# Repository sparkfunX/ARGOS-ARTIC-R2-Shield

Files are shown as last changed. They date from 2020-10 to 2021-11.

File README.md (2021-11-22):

# ARGOS Satellite Transceiver Shield

The [ARGOS ARTIC R2 satellite communication chipset](https://www.cls-telemetry.com/argos-solutions/argos-products/modems/artic-chipset/#1534863095666-398318f3-c367) in Thing Plus format.

SparkX ARGOS Satellite Transceiver Shield (https://www.sparkfun.com/products/17236)

[*SparkX ARGOS Satellite Transceiver Shield (SPX-17236)*](https://www.sparkfun.com/products/17236)

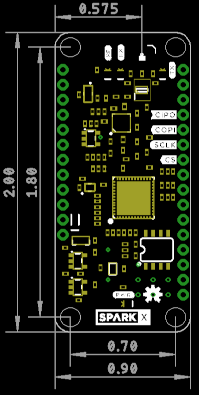
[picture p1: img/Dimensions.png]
Dimensions
_Dimensions are in inches_  

The ARTIC-R2 is an integrated low power small size ARGOS 2/3/4 single chip radio. ARTIC-R2 implements a message based wireless interface. For satellite uplink communication, ARTIC-R2 will encode, modulate and transmit provided user messages. For downlink communication, ARTIC-R2 will lock to the downstream, demodulate and decode it and extract the satellite messages.

The ARTIC-R2 can transmit signals in frequency bands around 400MHz and receive signals in the bands around 466MHz, in accordance with the ARGOS satellite system specifications. The ARTIC-R2 is compliant to all ARGOS 3 and ARGOS 4 RX and TX standards. It contains a RF transceiver and frequency synthesizer and a digital baseband modem. The ARTIC-R2 contains an on-chip power amplifier delivering 1mW [0dBm] output power, that serves as an output for connecting an external high efficient PA. The (de)modulation algorithms run on an on-chip DSP. This software approach allows for retargeting the ARTIC for other applications. The DSP program can be retained on an external flash or the MCU.

- Serial interface (SPI) for communication with MCU
- Programmable DSP core on board to ensure flexibility
- RX frequency : 466MHz – TX frequency: 400MHz
- Fractional N frequency synthesis
- Supported TX standards:
  - BPSK: PTT-A2 (ARGOS 2), PTT-VLD (ARGOS 4)
  - QPSK: PTT-A3, PTT-ZE (ARGOS 3)
  - GMSK: PTT-HD (ARGOS 3), PTT-MD (ARGOS 4), PTT-HD (ARGOS 4)
- Supported RX standards:
  - BPSK: PMT-A3 (ARGOS 3)
  - DSSS OQPSK: PMT-A4 (ARGOS 4) not available
- Dedicated flash Interface to retain Firmware
- Support COSPAS-SARSAT standard
- Operates on external 26MHz reference clock
- Dual supply, 1.8V and 3.3V
- Integrated PA (0dBm) to combine with external PA

An RFPA0133 programmable gain power amplifier boosts the 0dBm (1mW) output from the ARTIC by up to 26dB, producing a maximum transmit power level of 400mW. The transmit power can be adjusted via the **G8** breakout pin.

The ARGOS satellite system is **currently** restricted to specific programs and applications. Please check that your project meets these requirements before buying hardware. [CLS (France)](https://www.cls-telemetry.com/argos-solutions/) and the [Woods Hole Group (America)](https://www.clsamerica.com/science-with-argos) will be able to advise if your project meets the requirements.
- _**"To meet system use requirements, all programs using Argos have to be related in some way or other to environmental protection, awareness or study, or to protecting human life."**_

## Repository Contents

- [**/Documents**](./Documents) - Datasheets, test certificates etc.
- [**/Hardware**](./Hardware) - Eagle PCB, SCH and LBR design files
- [**LICENSE.md**](./LICENSE,md) - contains the licence information

## Documentation

- [**Arduino Library**](https://github.com/sparkfun/SparkFun_ARGOS_ARTIC_R2_Arduino_Library) - SparkFun ARGOS ARTIC R2 Arduino Library
- [**Hookup Guide**](https://learn.sparkfun.com/tutorials/argos-artic-r2-satellite-transceiver-shield-hookup-guide) - a hookup guide for the SparkFun ARGOS Satellite Transceiver Shield - ARTIC R2

## Thanks

The SparkX ARGOS Satellite Transceiver Shield is a remix of the reference design kindly provided by the Arribada Initiative and Icoteq Ltd.

## License Information

This product is _**open source**_! 

Please review the LICENSE.md file for license information. 

If you have any questions or concerns on licensing, please contact technical support on our [SparkFun forums](https://forum.sparkfun.com/viewforum.php?f=152).

Distributed as-is; no warranty is given.

- Your friends at SparkFun.

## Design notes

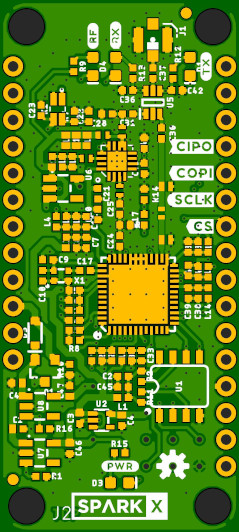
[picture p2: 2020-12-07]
img/Top.JPG

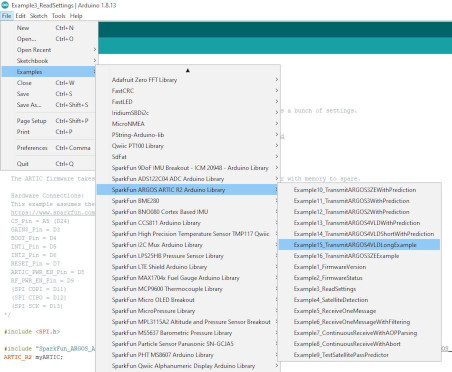
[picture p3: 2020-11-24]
img/HookUp3.JPG

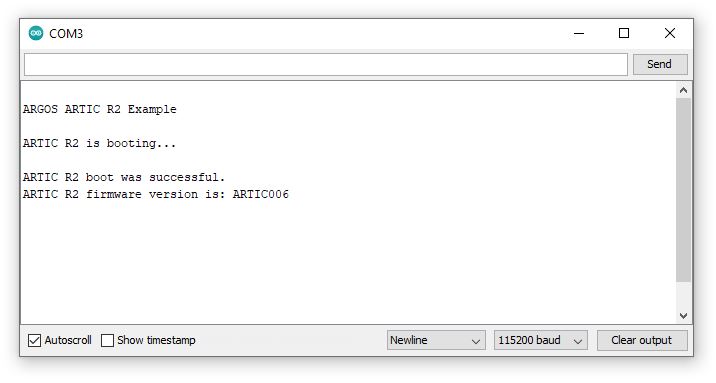
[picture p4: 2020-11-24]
img/HookUp6.JPG

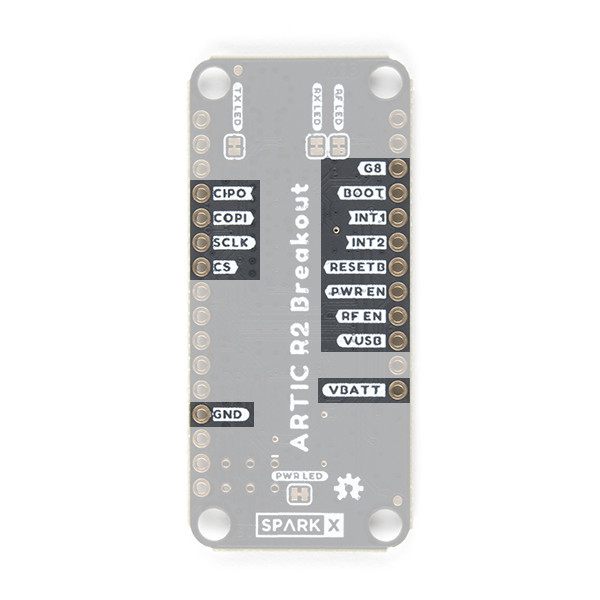
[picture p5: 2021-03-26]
img/17236-Artic_R2_Breakout-03.jpg

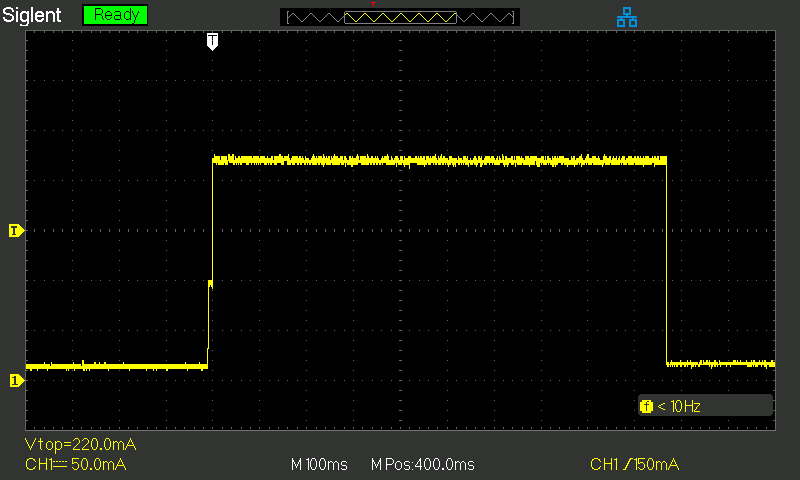
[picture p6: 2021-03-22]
img/TX_Current_ARGOS4VLD.png

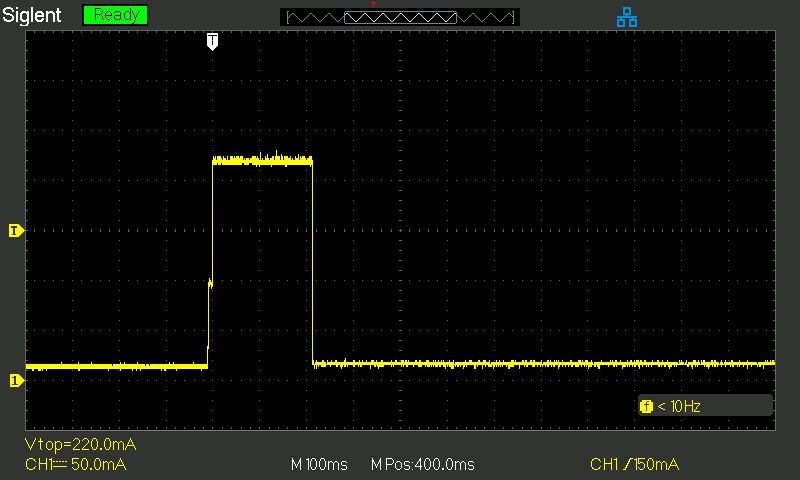
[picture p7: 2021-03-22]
img/TX_Current_ARGOS3ZE.png

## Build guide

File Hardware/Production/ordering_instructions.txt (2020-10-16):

JLCPCB JLC7628 4-Layer 0.8mm Impedance Control
panel size, 107x116mm
PCB thickness, 0.8mm
number of layers, 4
soldermask color, Black
silkscreen color, White
oz copper, 1oz
finish, ENIG
stencils, top
pcs per panel, 8
min trace width, 0.2032mm / 0.0080in
min drill size, 0.2000mm / 0.0079in
filename to layer stackup 1/2/3/4: GTL, GL2, GL3, GBL

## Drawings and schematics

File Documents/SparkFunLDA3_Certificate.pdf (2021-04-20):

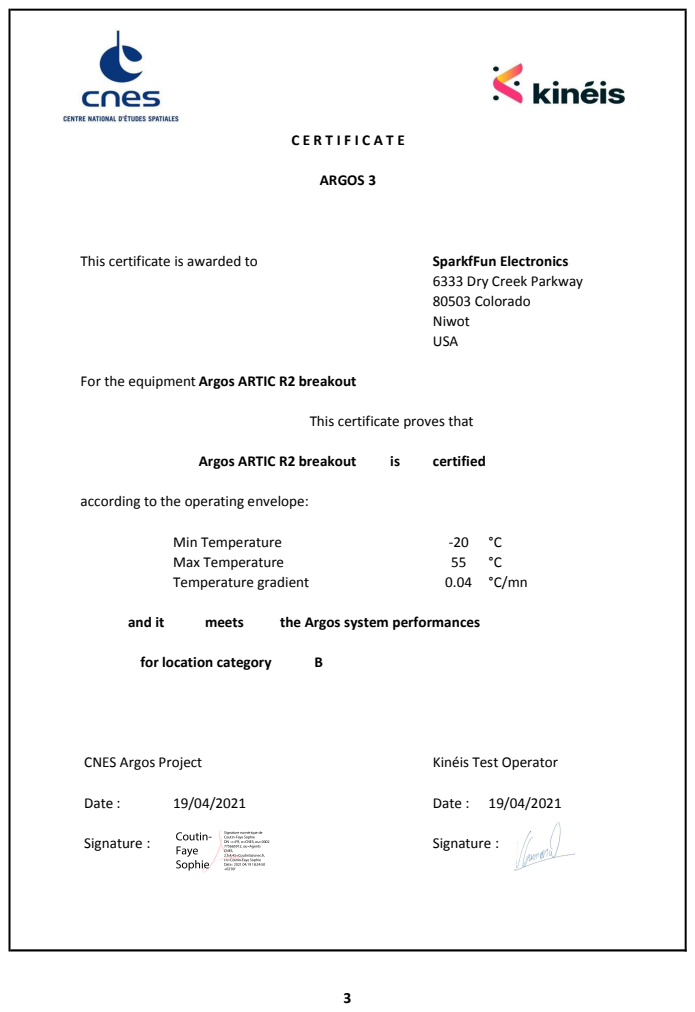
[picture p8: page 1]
This certificate is awarded to; SparkfFun Electronics; Argos ARTIC R2 breakout; certified; Min Temperature; Max Temperature; Temperature gradient; and it; meets; the Argos system performances; for location category; CNES Argos Project; Kinéis Test Operator; Date :; Date : 19/04/2021; Signature :; ARGOS 3

6333 Dry Creek Parkway
80503 Colorado
Niwot
USA

For the equipment Argos ARTIC R2 breakout

This certificate proves that

according to the operating envelope:

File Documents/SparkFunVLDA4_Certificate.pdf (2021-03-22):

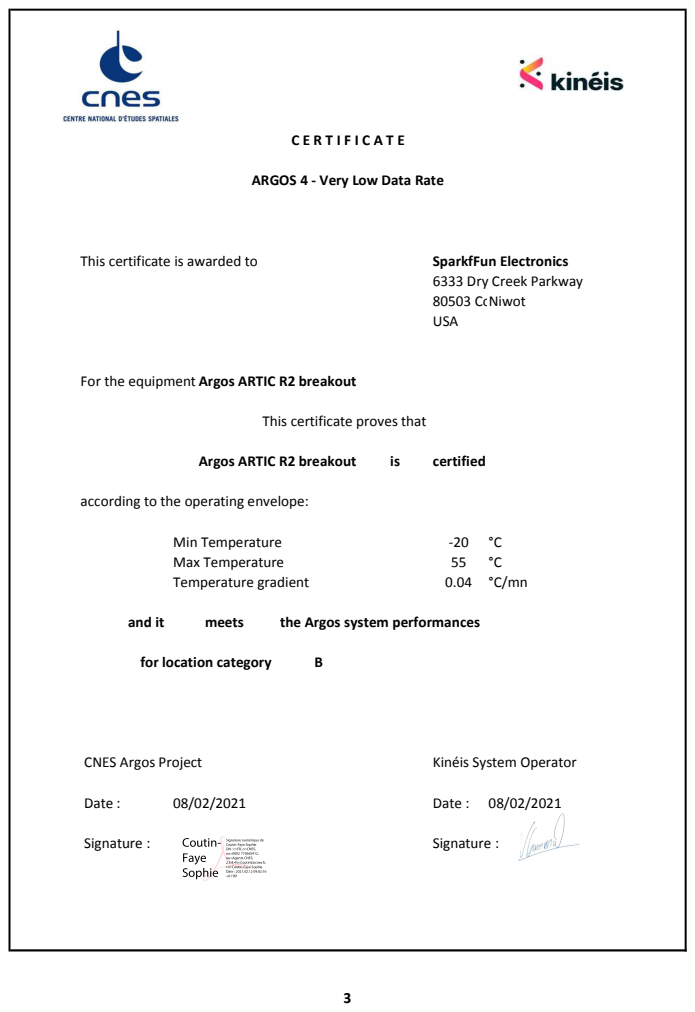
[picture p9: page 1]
This certificate is awarded to; SparkfFun Electronics; Argos ARTIC R2 breakout; certified; Min Temperature; Max Temperature; Temperature gradient; and it; meets; the Argos system performances; for location category; CNES Argos Project; Kinéis System Operator; Date :; Date : 08/02/2021; Signature :

ARGOS 4 - Very Low Data Rate

6333 Dry Creek Parkway
80503 Colorado Niwot
USA

For the equipment Argos ARTIC R2 breakout

This certificate proves that

according to the operating envelope:

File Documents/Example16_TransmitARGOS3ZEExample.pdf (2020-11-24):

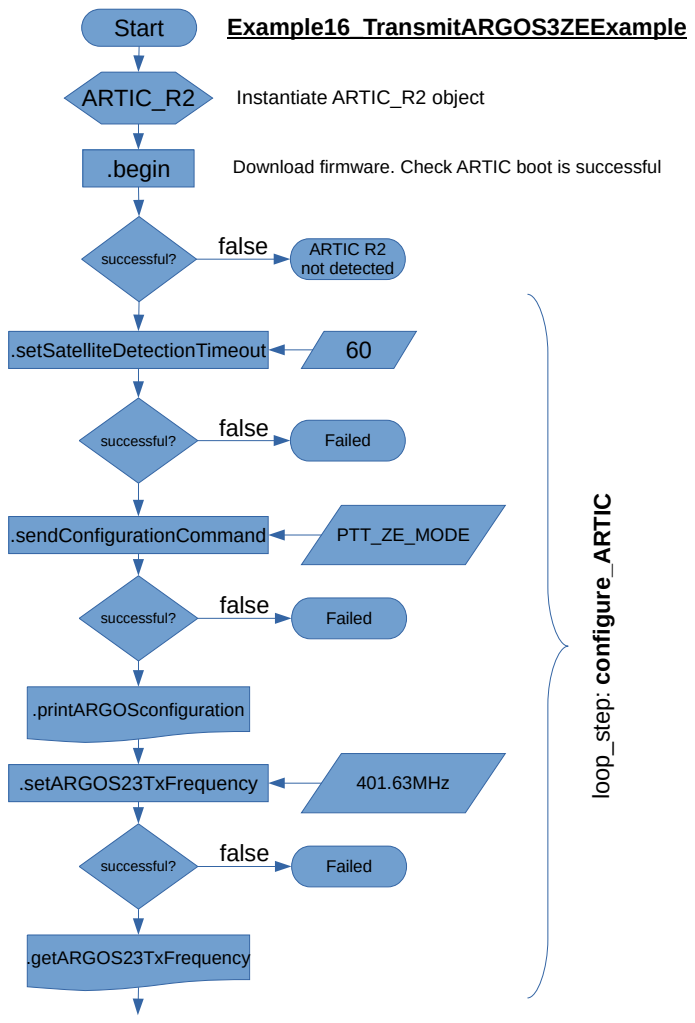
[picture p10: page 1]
Start; ARTIC_R2; Example16_TransmitARGOS3ZEExample; .begin; successful?; ARTIC R2; not detected; false; .setSatelliteDetectionTimeout; Failed false; .sendConfigurationCommand; PTT_ZE_MODE; .printARGOSconfiguration; .setARGOS23TxFrequency; 401.63MHz; .getARGOS23TxFrequency; Instantiate ARTIC_R2 object

Download firmware. Check ARTIC boot is successful

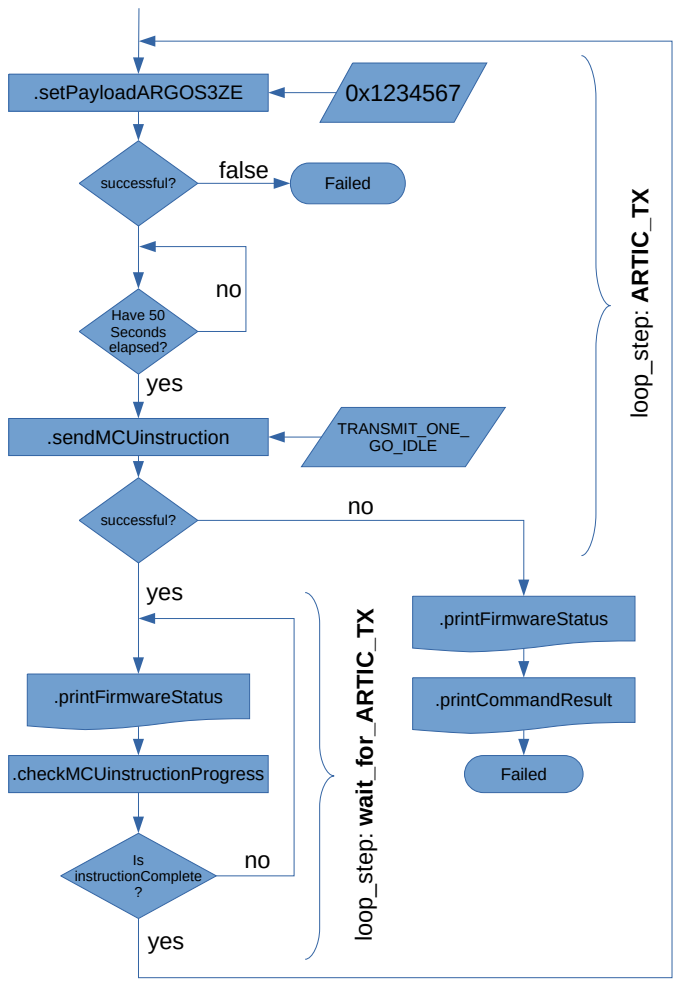
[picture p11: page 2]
.setPayloadARGOS3ZE; successful?; Failed false; Have 50 Seconds elapsed? yes; .sendMCUinstruction; TRANSMIT_ONE_; GO_IDLE; Failed; .printFirmwareStatus; .printCommandResult; yes; .checkMCUinstructionProgress; Is instructionComplete ?; ait_

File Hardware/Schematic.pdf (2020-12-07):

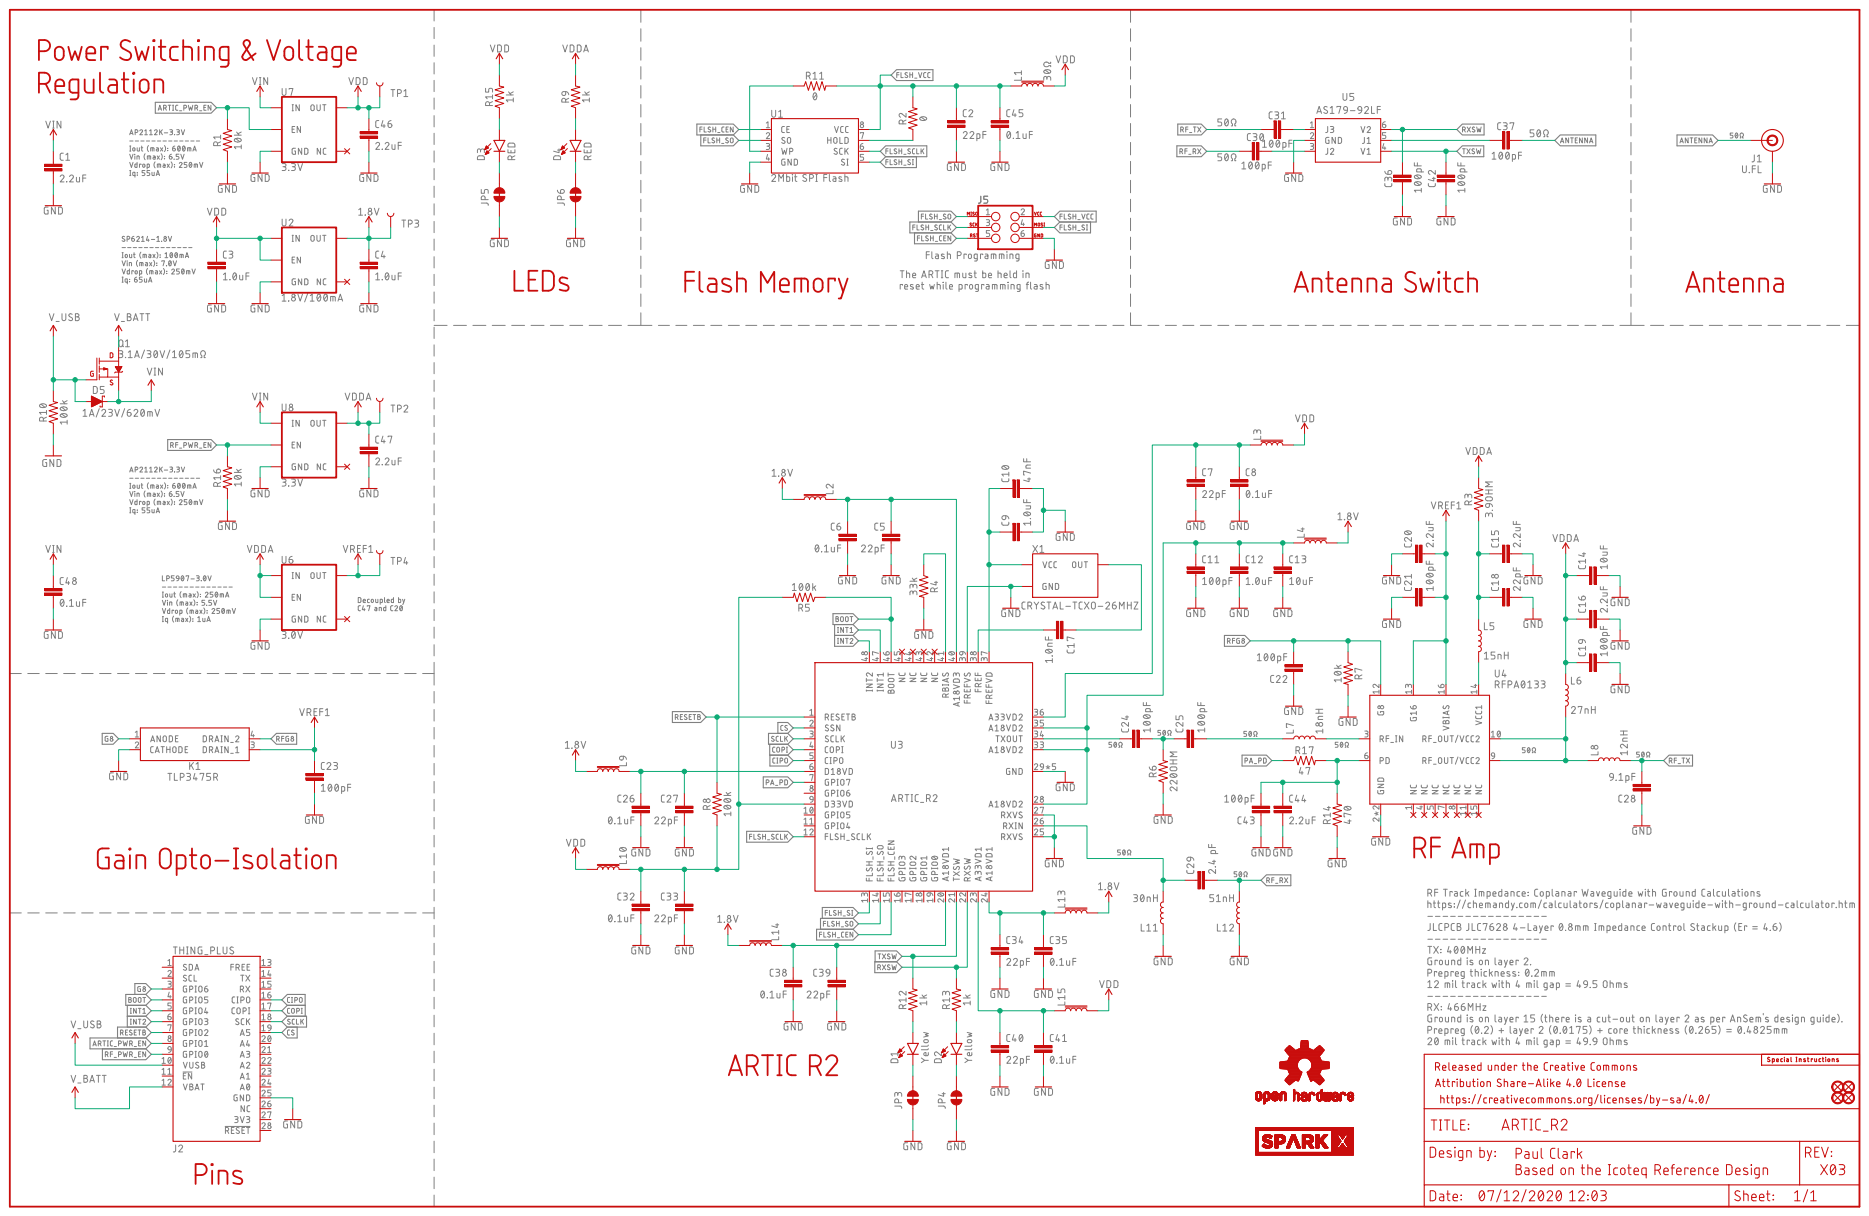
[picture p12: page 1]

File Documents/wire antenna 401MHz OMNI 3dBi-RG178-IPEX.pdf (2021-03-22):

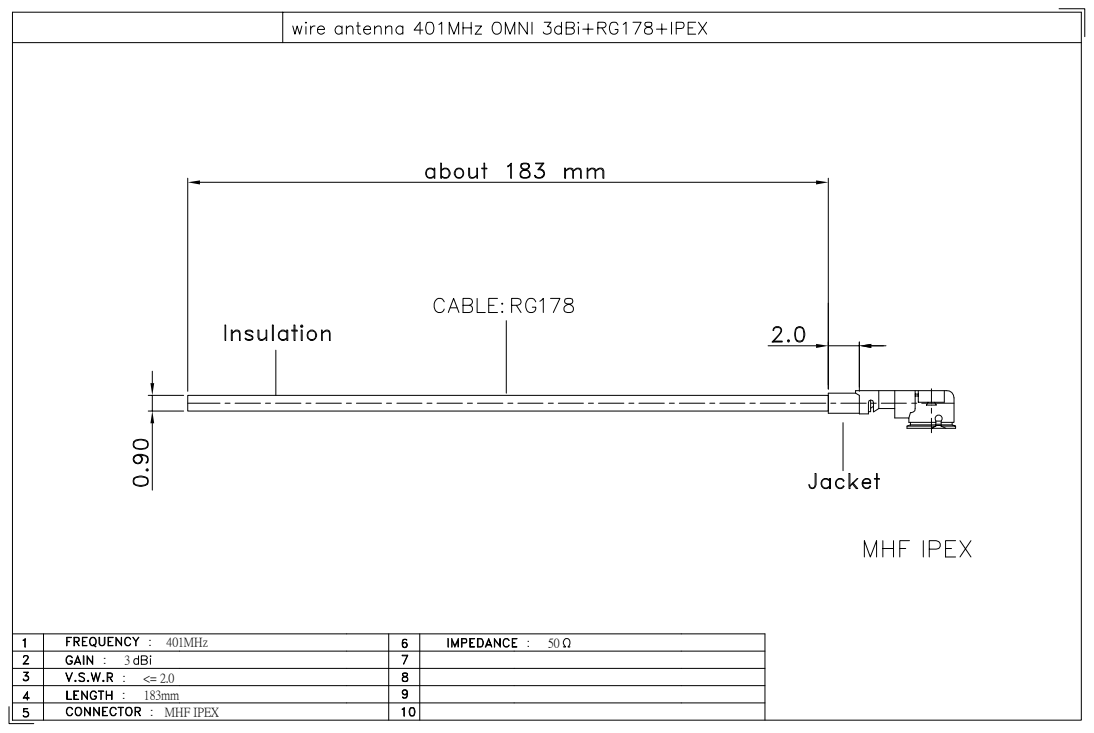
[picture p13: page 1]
: MHF IPEX; 401MHz

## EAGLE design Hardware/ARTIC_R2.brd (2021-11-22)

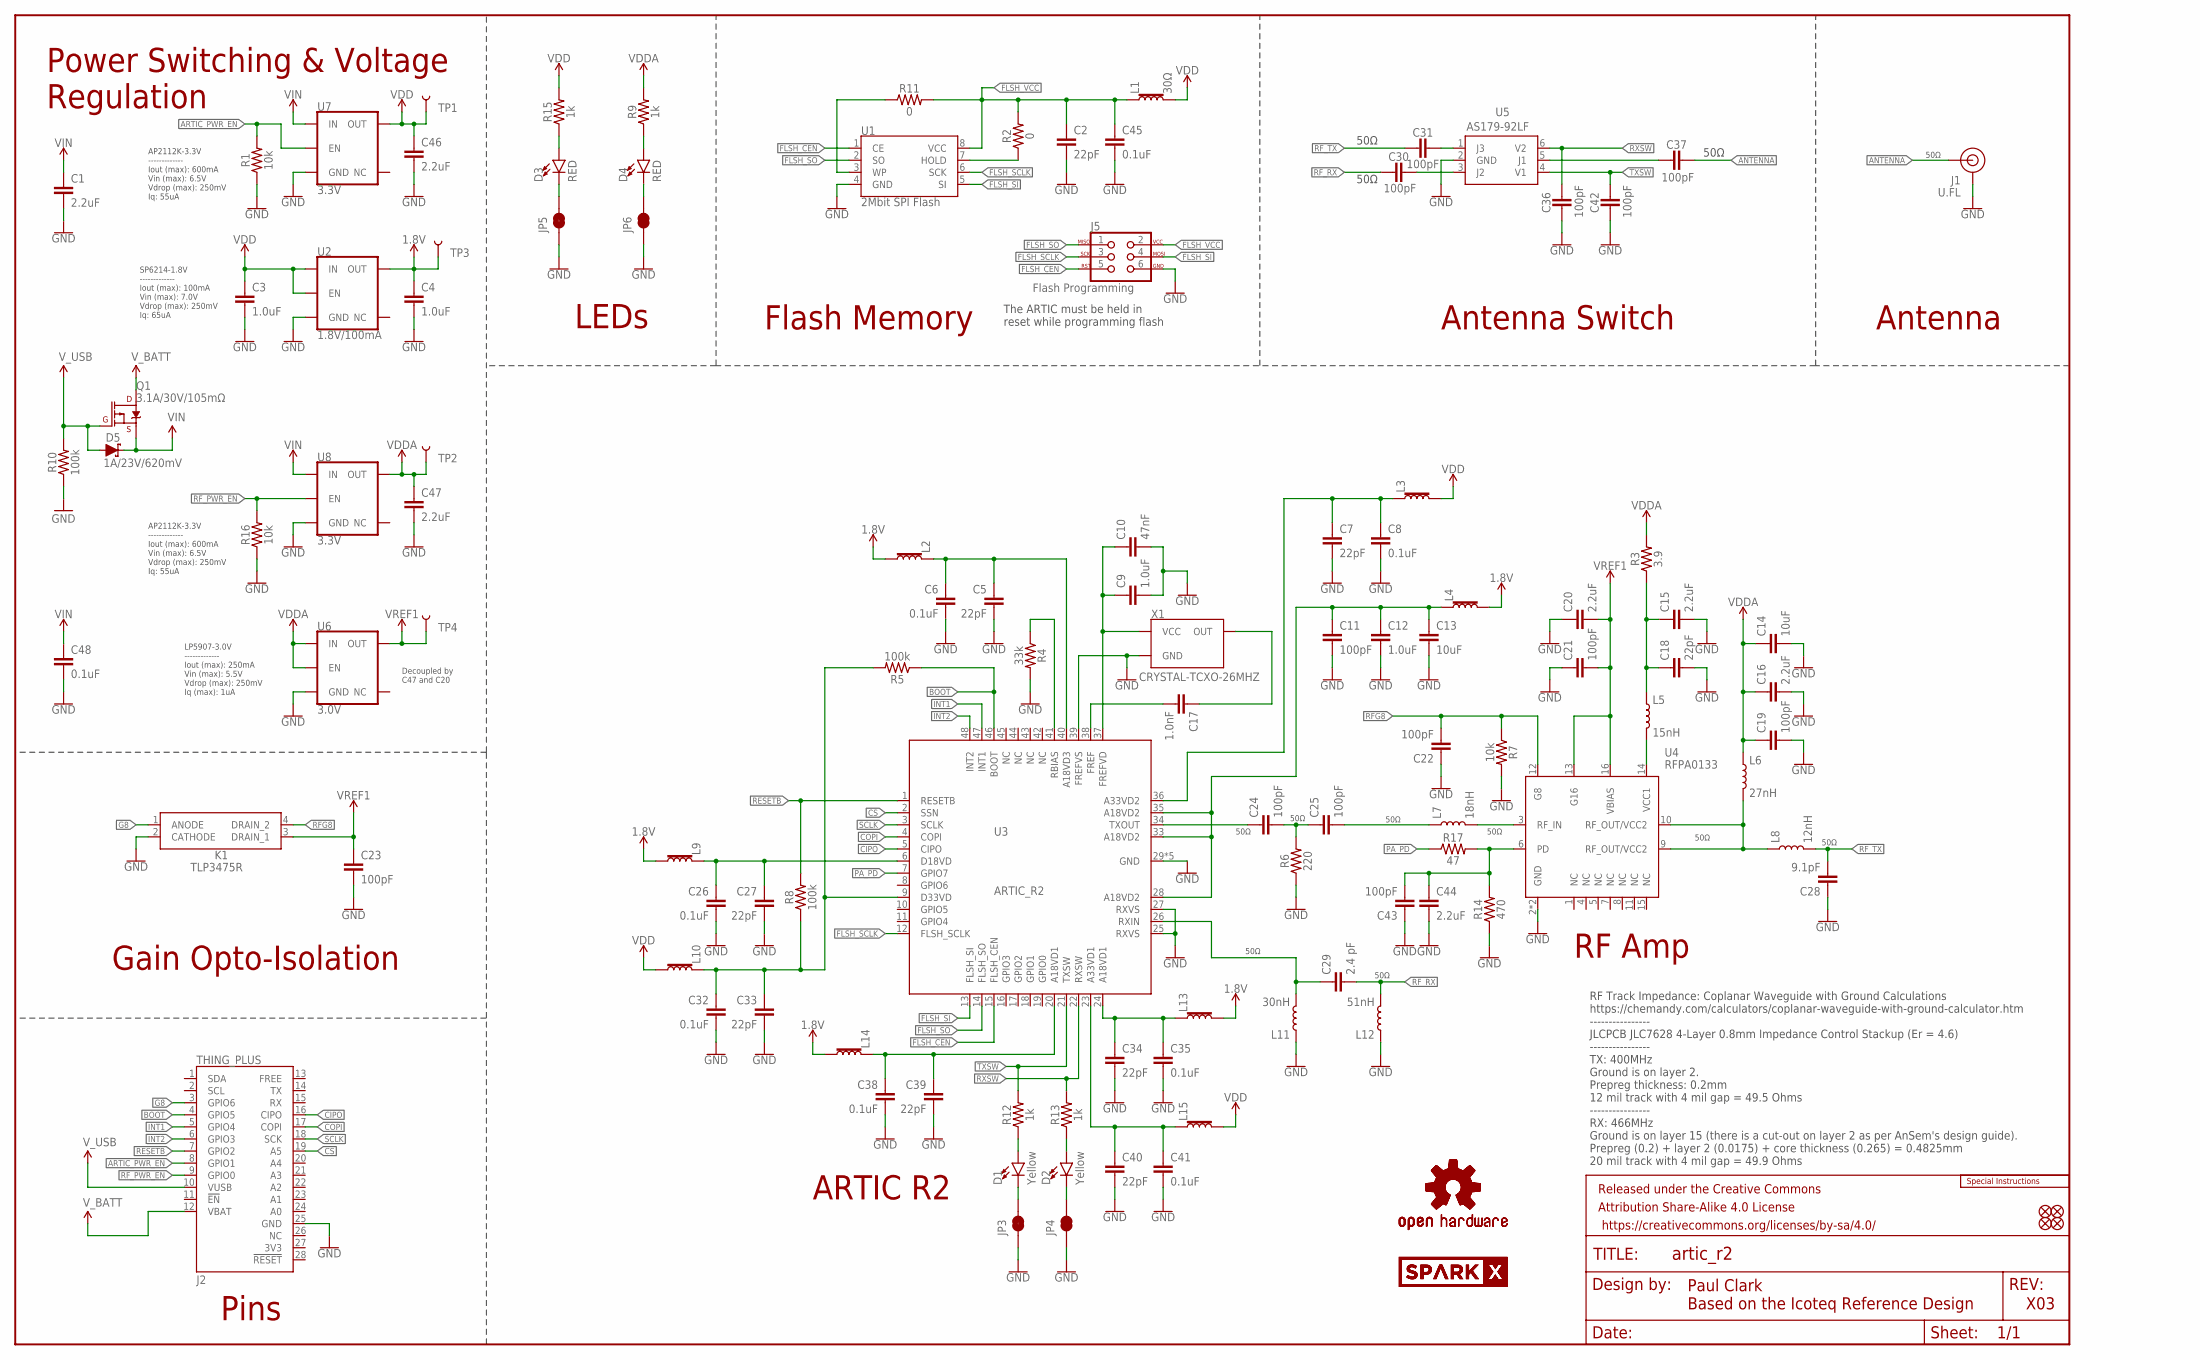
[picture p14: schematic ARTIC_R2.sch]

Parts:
C1, C15, C16, C20, C44, C46, C47: 2.2uF; 0402-TIGHT
C2, C5, C7, C18, C27, C33, C34, C39, C40: 22pF; 0402-TIGHT
C3, C4, C9, C12: 1.0uF; 0402-TIGHT
C6, C8, C26, C32, C35, C38, C41, C45, C48: 0.1uF; 0402-TIGHT
C10: 47nF; 0402-TIGHT
C11, C19, C21, C22, C23, C24, C25, C30, C31, C36, C37, C42, C43: 100pF; 0402-TIGHT
C13, C14: 10uF; 0402-TIGHT
C17: 1.0nF; 0402-TIGHT
C28: 9.1pF; 0402-TIGHT
C29: 2.4 pF; 0402_MURATA
D1, D2: Yellow; LED-0603
D3, D4: RED; LED-0603
D5: 1A/23V/620mV; SOD-323
FD1, FD2, FD3, FD4: FIDUCIAL1X2; FIDUCIAL-1X2
FRAME1: FRAME-LEDGER; CREATIVE_COMMONS
J1: U.FL
J2: THING_PLUS
J5: Flash Programming; 2X3_TEST_POINTS
JP3, JP4, JP5, JP6: JUMPER-SMT_2_NC_TRACE_SILK; SMT-JUMPER_2_NC_TRACE_SILK
K1: TLP3475R; TLP3475RTPF
L1, L2, L3, L4, L9, L10, L13, L14, L15: 30Ω; 0402-TIGHT
L5: 15nH; 0402_COILCRAFT
L6: 27nH; 0402_COILCRAFT
L7: 18nH; 0402_COILCRAFT
L8: 12nH; 0402_COILCRAFT
L11: 30nH; 0402_COILCRAFT
L12: 51nH; 0402_COILCRAFT
LOGO1: SPECIAL_INSTRUCTIONS-ORDERING; ORDERING_INSTRUCTIONS
LOGO2, LOGO3: OSHW-LOGOS; OSHW-LOGO-S
Q1: 3.1A/30V/105mΩ; SOT23-3
R1, R7, R16: 10k; 0402-TIGHT
R2, R11: 0; 0402-TIGHT
R3: 3.9; 0402-TIGHT
R4: 33k; 0402-TIGHT
R5, R8, R10: 100k; 0402-TIGHT
R6: 220; 0402-TIGHT
R9, R12, R13, R15: 1k; 0402-TIGHT
R14: 470; 0402-TIGHT
R17: 47; 0402-TIGHT
SPARKX1, SPARKX2: SPARKX-LOGO4; SPARKX-MEDIUM
TP1, TP2, TP3, TP4: TEST-POINTTP_15TH_THRU; TP_15TH
U1: 2Mbit SPI Flash; SO08
U2: 1.8V/100mA; SC70
U3: ARTIC_R2; QFN-48
U4: RFPA0133; QFN50P300X300X86-17N
U5: AS179-92LF; SOT65P220X100-6N
U6: 3.0V; SOT23-5
U7, U8: 3.3V; SOT23-5
X1: CRYSTAL-TCXO-26MHZ; CRYSTAL-TCXO-SMD-1.65X1.25

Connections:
1.8V: C4.1, L2.2, L4.2, L9.2, L13.2, L14.2, TP3.P$1, U2.5 (OUT)
ANTENNA: C37.1, J1.FEED (SIGNAL)
ARTIC_PWR_EN: J2.8 (GPIO1), R1.2, U7.3 (EN)
BOOT: J2.4 (GPIO5), R5.1, U3.46 (BOOT)
CIPO: J2.16 (CIPO), U3.5 (CIPO)
COPI: J2.17 (COPI), U3.4 (COPI)
CS: J2.19 (A5), U3.2 (SSN)
FLSH_CEN: J5.5, U1.1 (CE), U3.15 (FLSH_CEN)
FLSH_SCLK: J5.3, U1.6 (SCK), U3.12 (FLSH_SCLK)
FLSH_SI: J5.4, U1.5 (SI), U3.13 (FLSH_SI)
FLSH_SO: J5.1, U1.2 (SO), U3.14 (FLSH_SO)
FLSH_VCC: C2.1, C45.1, J5.2, L1.1, R2.2, R11.2, U1.8 (VCC)
G8: J2.3 (GPIO6), K1.1 (ANODE)
GND: C1.2, C2.2, C3.2, C4.2, C5.2, C6.2, C7.2, C8.2, C9.2, C10.2, C11.2, C12.2, C13.2, C14.2, C15.2, C16.2, C18.2, C19.2, C20.1, C21.1, C22.1, C23.2, C26.2, C27.2, C28.1, C32.2, C33.2, C34.2, C35.2, C36.2, C38.2, C39.2, C40.2, C41.2, C42.2, C43.1, C44.2, C45.2, C46.2, C47.2, C48.2, J1.1 (GND), J1.2 (GND), J2.25 (GND), J5.6, JP3.1, JP4.1, JP5.1, JP6.1, K1.2 (CATHODE), L11.P$1 (1), L12.P$1 (1), R1.1, R4.2, R6.1, R7.2, R10.1, R14.1, R16.1, U1.4 (GND), U2.2 (GND), U3.25 (RXVS), U3.27 (RXVS), U3.29 (GND), U3.30 (GND), U3.31 (GND), U3.32 (GND), U3.39 (FREFVS), U3.GND, U4.2 (GND), U4.EDAP (GND), U5.2 (GND), U6.2 (GND), U7.2 (GND), U8.2 (GND), X1.1 (GND), X1.2 (GND)
INT1: J2.5 (GPIO4), U3.47 (INT1)
INT2: J2.6 (GPIO3), U3.48 (INT2)
unnamed: R2.1, U1.7 (HOLD)
unnamed: R11.1, U1.3 (WP)
unnamed: C34.1, C35.1, L13.1, U3.24 (A18VD1)
unnamed: C40.1, C41.1, L15.1, U3.23 (A33VD1)
unnamed: D2.A, R13.1
unnamed: D1.A, R12.1
unnamed: C26.1, C27.1, L9.1, U3.6 (D18VD)
unnamed: C32.1, C33.1, L10.1, R5.2, R8.1, U3.9 (D33VD)
unnamed: C11.1, C12.1, C13.1, L4.1, U3.28 (A18VD2), U3.33 (A18VD2), U3.35 (A18VD2)
unnamed: C7.1, C8.1, L3.1, U3.36 (A33VD2)
unnamed: R4.1, U3.41 (RBIAS)
unnamed: C5.1, C6.1, L2.1, U3.40 (A18VD3)
unnamed: C9.1, C10.1, U3.37 (FREFVD), X1.4 (VCC)
unnamed: C17.1, X1.3 (OUT)
unnamed: C17.2, U3.38 (FREF)
unnamed: C24.1, U3.34 (TXOUT)
unnamed: C24.2, C25.1, R6.2
unnamed: L5.P$2 (2), U4.14 (VCC1)
unnamed: C15.1, C18.1, L5.P$1 (1), R3.1
unnamed: C29.P$1 (1), L11.P$2 (2), U3.26 (RXIN)
unnamed: D4.A, R9.1
unnamed: C25.2, L7.P$1 (1)
unnamed: L7.P$2 (2), U4.3 (RF_IN)
unnamed: L6.P$2 (2), L8.P$1 (1), U4.9 (RF_OUT/VCC2), U4.10 (RF_OUT/VCC2)
unnamed: D4.C, JP6.2
unnamed: C31.1, U5.1 (J3)
unnamed: C30.1, U5.3 (J2)
unnamed: C37.2, U5.5 (J1)
unnamed: C38.1, C39.1, L14.1, U3.20 (A18VD1)
unnamed: D1.C, JP3.2
unnamed: D2.C, JP4.2
unnamed: D3.A, R15.1
unnamed: D3.C, JP5.2
PA_PD: R17.1, U3.7 (GPIO7)
PD: C43.2, C44.1, R14.2, R17.2, U4.6 (PD)
RESETB: J2.7 (GPIO2), R8.2, U3.1 (RESETB)
RFG8: C22.2, K1.4 (DRAIN_2), R7.1, U4.12 (G8)
RF_PWR_EN: J2.9 (GPIO0), R16.2, U8.3 (EN)
RF_RX: C29.P$2 (2), C30.2, L12.P$2 (2)
RF_TX: C28.2, C31.2, L8.P$2 (2)
RXSW: C36.1, R13.2, U3.22 (RXSW), U5.6 (V2)
SCLK: J2.18 (SCK), U3.3 (SCLK)
TXSW: C42.1, R12.2, U3.21 (TXSW), U5.4 (V1)
VDD: C3.1, C46.1, L1.2, L3.2, L10.2, L15.2, R15.2, TP1.P$1, U2.1 (IN), U2.3 (EN), U7.5 (OUT)
VDDA: C14.1, C16.1, C19.1, C47.1, L6.P$1 (1), R3.2, R9.2, TP2.P$1, U6.1 (IN), U6.3 (EN), U8.5 (OUT)
VIN: C1.1, C48.1, D5.C, Q1.2 (S), U7.1 (IN), U8.1 (IN)
VREF1: C20.2, C21.2, C23.1, K1.3 (DRAIN_1), TP4.P$1, U4.13 (G16), U4.16 (VBIAS), U6.5 (OUT)
V_BATT: J2.12 (VBAT), Q1.3 (D)
V_USB: D5.A, J2.10 (VUSB), Q1.1 (G), R10.2

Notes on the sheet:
Paul Clark Based on the Icoteq Reference Design
X03
SP6214-1.8V ------------- Iout (max): 100mA Vin (max): 7.0V Vdrop (max): 250mV Iq: 65uA
Power Switching & Voltage Regulation
Flash Memory
Antenna Switch
Antenna
ARTIC R2
RF Amp
Pins
50Ω
LEDs
RF Track Impedance: Coplanar Waveguide with Ground Calculations https://chemandy.com/calculators/coplanar-waveguide-with-ground-calculator.htm ---------------- JLCPCB JLC7628 4-Layer 0.8mm Impedance Control Stackup (Er = 4.6) ---------------- TX: 400MHz Ground is on layer 2. Prepreg thickness: 0.2m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
Gain Opto-Isolation
The ARTIC must be held in reset while programming flash
AP2112K-3.3V ------------- Iout (max): 600mA Vin (max): 6.5V Vdrop (max): 250mV Iq: 55uA
LP5907-3.0V ------------- Iout (max): 250mA Vin (max): 5.5V Vdrop (max): 250mV Iq (max): 1uA
Decoupled by C47 and C20

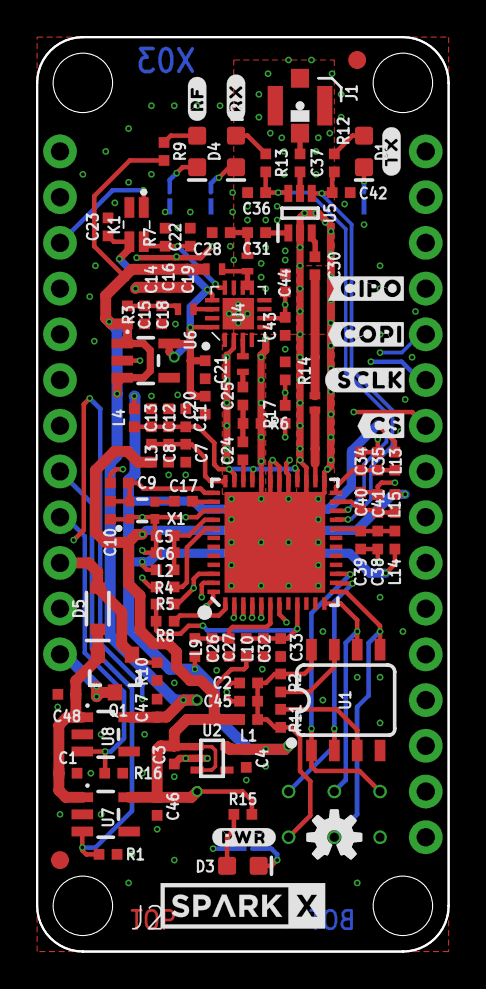
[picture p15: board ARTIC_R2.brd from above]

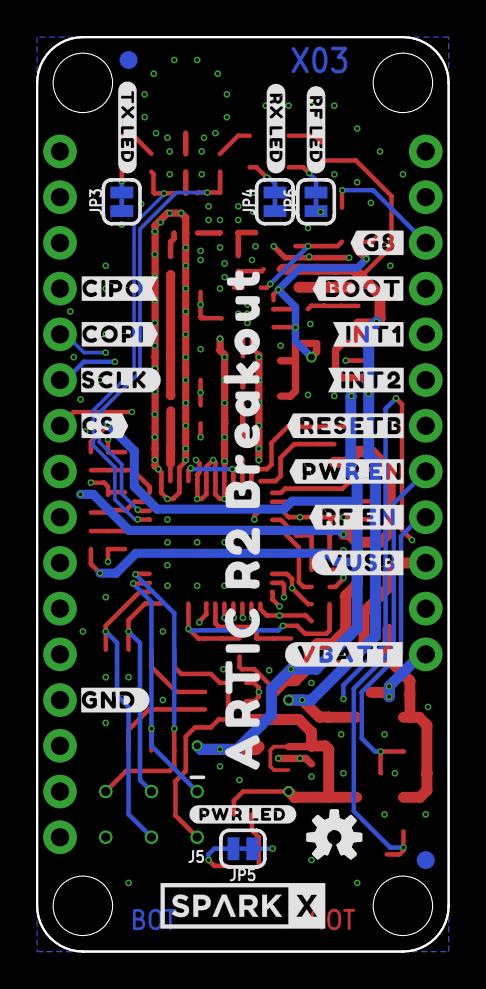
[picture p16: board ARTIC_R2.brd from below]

Board: 4 copper layers, 22.9 x 50.8 mm, 144 parts (28 on the bottom side), 65 nets.

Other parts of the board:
U$1: #TX#0
U$2: #RX#0
U$3: #RX_LED#0
U$4: #TX_LED#0
U$5: #RF_LED#0
U$6: #G8#0
U$7: #RF#0
U$8: #RF_EN#0
U$9: CIPO#0
U$10: #CIPO0
U$11: #COPI0
U$12: COPI#0
U$13: #SCLK0
U$14: SCLK#0
U$15: #CS0
U$16: CS#0
U$17: GND#0
U$18: #RESETB0
U$19: #PWR_EN0
U$20: #VBATT#0
U$21: #VUSB#0
U$24: #BOOT0
U$25: #INT10
U$26: #INT20
U$27: #PWR_LED#0
U$28: #PWR#0
U$29: ARTIC_R2_BREAKOUT0

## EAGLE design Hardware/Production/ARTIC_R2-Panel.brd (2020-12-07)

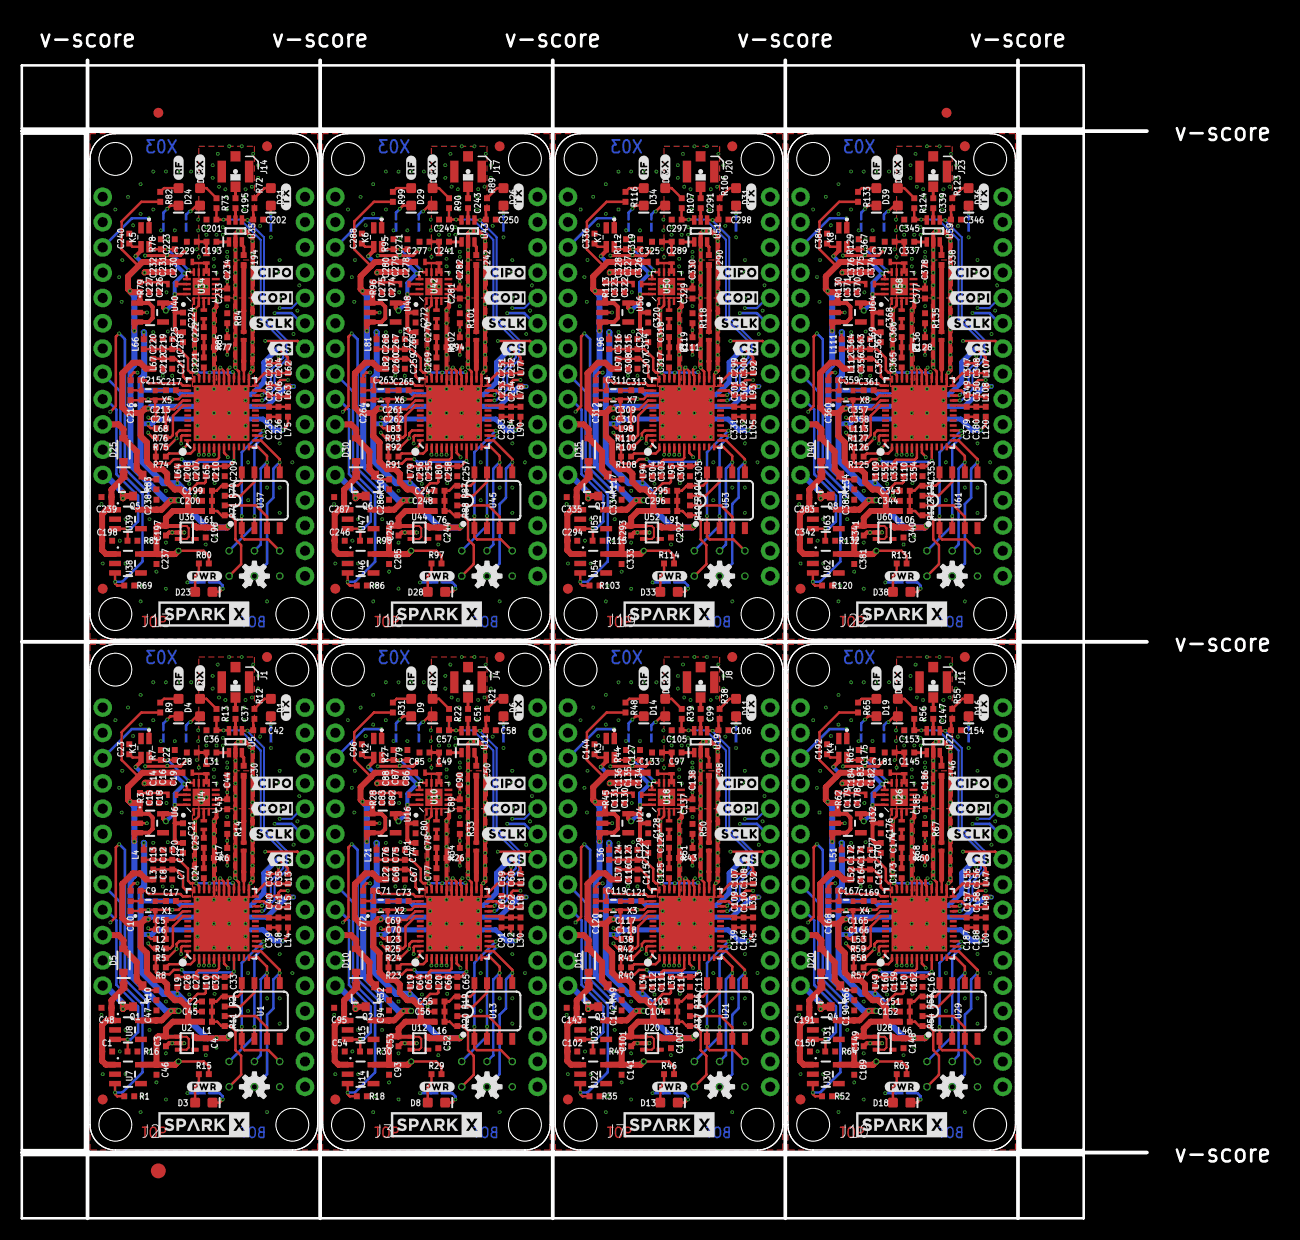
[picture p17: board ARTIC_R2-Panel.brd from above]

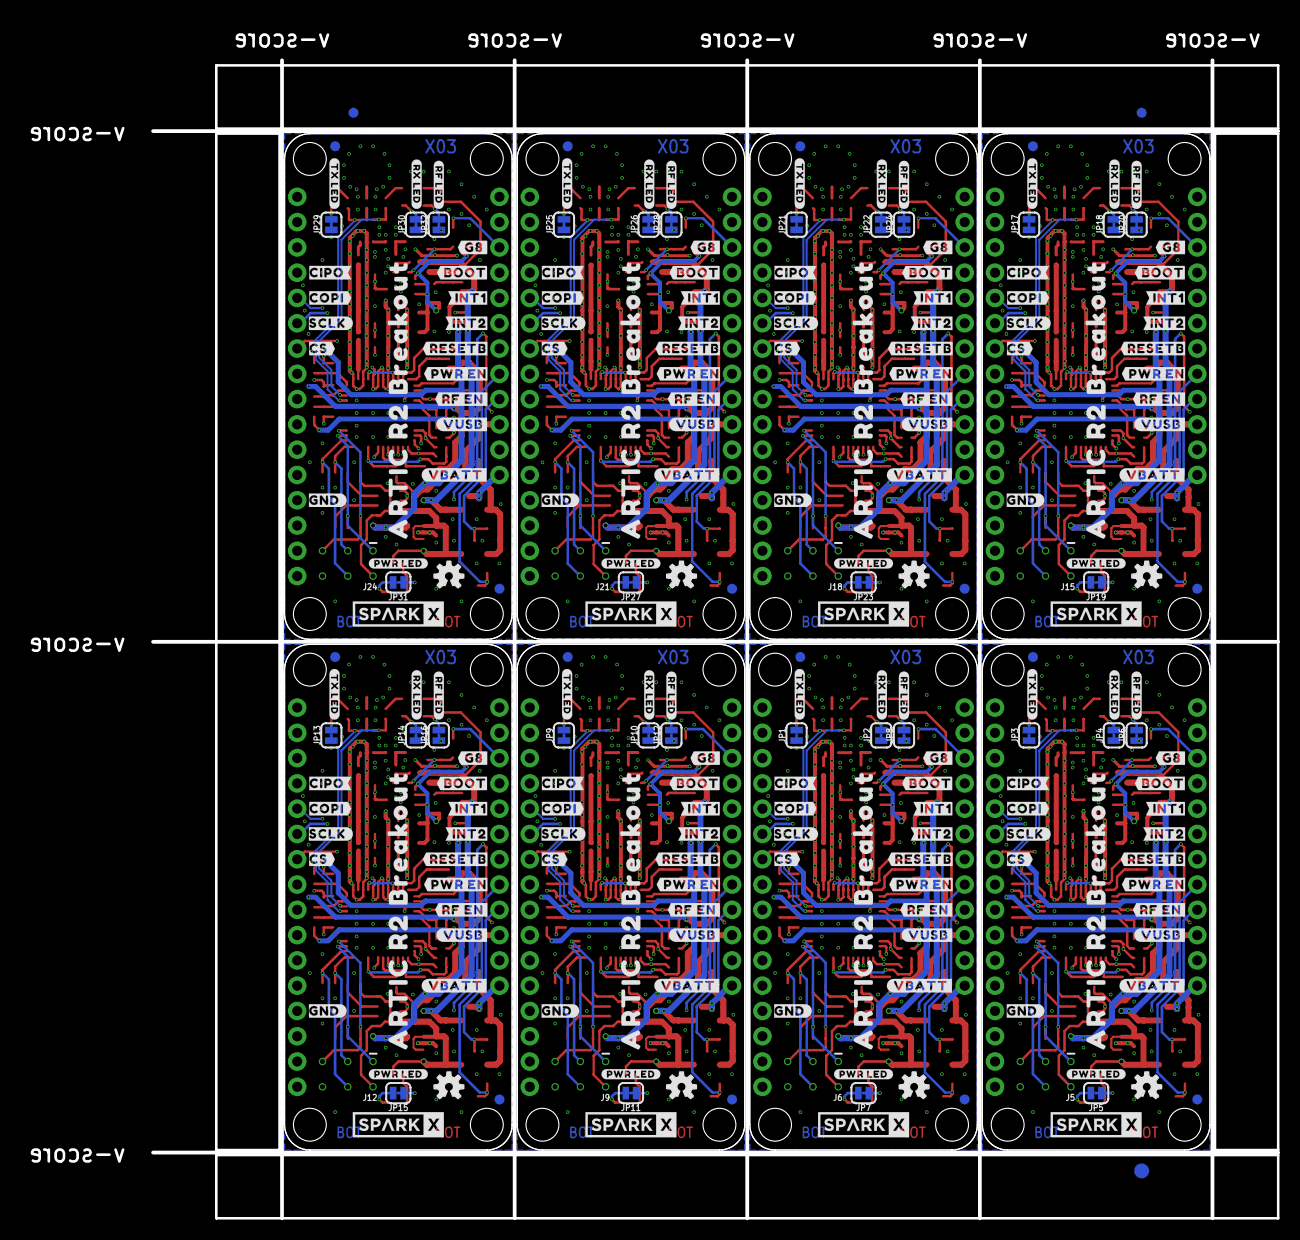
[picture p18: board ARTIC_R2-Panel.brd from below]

Board: 4 copper layers, 113.0 x 116.3 mm, 1142 parts (227 on the bottom side), 520 nets.

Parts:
C1, C15, C16, C20, C44, C46, C47, C54, C81, C83, C87, C90, C93, C94, C102, C129, C131, C135, C138, C141, C142, C150, C177, C179, C183, C186, C189, C190, C198, C225, C227, C231, C234, C237, C238, C246, C273, C275, C279, C282, C285, C286, C294, C321, C323, C327, C330, C333, C334, C342, C369, C371, C375, C378, C381, C382: 2.2uF; 0402-TIGHT
C2, C5, C7, C18, C27, C33, C34, C39, C40, C55, C59, C61, C63, C65, C67, C69, C82, C91, C103, C107, C109, C111, C113, C115, C117, C130, C139, C151, C155, C157, C159, C161, C163, C165, C178, C187, C199, C203, C205, C207, C209, C211, C213, C226, C235, C247, C251, C253, C255, C257, C259, C261, C274, C283, C295, C299, C301, C303, C305, C307, C309, C322, C331, C343, C347, C349, C351, C353, C355, C357, C370, C379: 22pF; 0402-TIGHT
C3, C4, C9, C12, C52, C53, C71, C75, C100, C101, C119, C123, C148, C149, C167, C171, C196, C197, C215, C219, C244, C245, C263, C267, C292, C293, C311, C315, C340, C341, C359, C363: 1.0uF; 0402-TIGHT
C6, C8, C26, C32, C35, C38, C41, C45, C48, C56, C60, C62, C64, C66, C68, C70, C92, C95, C104, C108, C110, C112, C114, C116, C118, C140, C143, C152, C156, C158, C160, C162, C164, C166, C188, C191, C200, C204, C206, C208, C210, C212, C214, C236, C239, C248, C252, C254, C256, C258, C260, C262, C284, C287, C296, C300, C302, C304, C306, C308, C310, C332, C335, C344, C348, C350, C352, C354, C356, C358, C380, C383: 0.1uF; 0402-TIGHT
C10, C72, C120, C168, C216, C264, C312, C360: 47nF; 0402-TIGHT
C11, C19, C21, C22, C23, C24, C25, C30, C31, C36, C37, C42, C43, C49, C50, C51, C57, C58, C74, C77, C78, C79, C80, C86, C89, C96, C97, C98, C99, C105, C106, C122, C125, C126, C127, C128, C134, C137, C144, C145, C146, C147, C153, C154, C170, C173, C174, C175, C176, C182, C185, C192, C193, C194, C195, C201, C202, C218, C221, C222, C223, C224, C230, C233, C240, C241, C242, C243, C249, C250, C266, C269, C270, C271, C272, C278, C281, C288, C289, C290, C291, C297, C298, C314, C317, C318, C319, C320, C326, C329, C336, C337, C338, C339, C345, C346, C362, C365, C366, C367, C368, C374, C377, C384: 100pF; 0402-TIGHT
C13, C14, C76, C88, C124, C136, C172, C184, C220, C232, C268, C280, C316, C328, C364, C376: 10uF; 0402-TIGHT
C17, C73, C121, C169, C217, C265, C313, C361: 1.0nF; 0402-TIGHT
C28, C85, C133, C181, C229, C277, C325, C373: 9.1pF; 0402-TIGHT
C29, C84, C132, C180, C228, C276, C324, C372: 2.4 pF; 0402_MURATA
D1, D2, D6, D7, D11, D12, D16, D17, D21, D22, D26, D27, D31, D32, D36, D37: Yellow; LED-0603
D3, D4, D8, D9, D13, D14, D18, D19, D23, D24, D28, D29, D33, D34, D38, D39: RED; LED-0603
D5, D10, D15, D20, D25, D30, D35, D40: 1A/23V/620mV; SOD-323
E$1, E$2, E$3, E$4: FIDUCIAL-1X2
E$5, E$6: FIDUCIAL-1.5X3
FD1, FD2, FD3, FD4, FD5, FD6, FD7, FD8, FD9, FD10, FD11, FD12, FD13, FD14, FD15, FD16, FD17, FD18, FD19, FD20, FD21, FD22, FD23, FD24, FD25, FD26, FD27, FD28, FD29, FD30, FD31, FD32: FIDUCIAL1X2; FIDUCIAL-1X2
J1, J4, J8, J11, J14, J17, J20, J23: U.FL
J2, J3, J7, J10, J13, J16, J19, J22: THING_PLUS
J5, J6, J9, J12, J15, J18, J21, J24: Flash Programming; 2X3_TEST_POINTS
JP1, JP2, JP3, JP4, JP5, JP6, JP7, JP8, JP9, JP10, JP11, JP12, JP13, JP14, JP15, JP16, JP17, JP18, JP19, JP20, JP21, JP22, JP23, JP24, JP25, JP26, JP27, JP28, JP29, JP30, JP31, JP32: JUMPER-SMT_2_NC_TRACE_SILK; SMT-JUMPER_2_NC_TRACE_SILK
K1, K2, K3, K4, K5, K6, K7, K8: TLP3475R; TLP3475RTPF
L1, L2, L3, L4, L9, L10, L13, L14, L15, L16, L17, L18, L19, L20, L21, L22, L23, L30, L31, L32, L33, L34, L35, L36, L37, L38, L45, L46, L47, L48, L49, L50, L51, L52, L53, L60, L61, L62, L63, L64, L65, L66, L67, L68, L75, L76, L77, L78, L79, L80, L81, L82, L83, L90, L91, L92, L93, L94, L95, L96, L97, L98, L105, L106, L107, L108, L109, L110, L111, L112, L113, L120: 30Ω; 0402-TIGHT
L5, L25, L40, L55, L70, L85, L100, L115: 15nH; 0402_COILCRAFT
L6, L26, L41, L56, L71, L86, L101, L116: 27nH; 0402_COILCRAFT
L7, L24, L39, L54, L69, L84, L99, L114: 18nH; 0402_COILCRAFT
L8, L27, L42, L57, L72, L87, L102, L117: 12nH; 0402_COILCRAFT
L11, L28, L43, L58, L73, L88, L103, L118: 30nH; 0402_COILCRAFT
L12, L29, L44, L59, L74, L89, L104, L119: 51nH; 0402_COILCRAFT
LOGO1, LOGO2, LOGO3, LOGO4, LOGO5, LOGO6, LOGO7, LOGO8, LOGO9, LOGO10, LOGO11, LOGO12, LOGO13, LOGO14, LOGO15, LOGO16: OSHW-LOGOS; OSHW-LOGO-S
Q1, Q2, Q3, Q4, Q5, Q6, Q7, Q8: 3.1A/30V/105mΩ; SOT23-3
R1, R7, R16, R18, R27, R30, R35, R44, R47, R52, R61, R64, R69, R78, R81, R86, R95, R98, R103, R112, R115, R120, R129, R132: 10k; 0402-TIGHT
R2, R11, R19, R20, R36, R37, R53, R54, R70, R71, R87, R88, R104, R105, R121, R122: 0; 0402-TIGHT
R3, R28, R45, R62, R79, R96, R113, R130: 3.9OHM; 0402-TIGHT
R4, R25, R42, R59, R76, R93, R110, R127: 33k; 0402-TIGHT
R5, R8, R10, R23, R24, R32, R40, R41, R49, R57, R58, R66, R74, R75, R83, R91, R92, R100, R108, R109, R117, R125, R126, R134: 100k; 0402-TIGHT
R6, R26, R43, R60, R77, R94, R111, R128: 220OHM; 0402-TIGHT
R9, R12, R13, R15, R21, R22, R29, R31, R38, R39, R46, R48, R55, R56, R63, R65, R72, R73, R80, R82, R89, R90, R97, R99, R106, R107, R114, R116, R123, R124, R131, R133: 1k; 0402-TIGHT
R14, R33, R50, R67, R84, R101, R118, R135: 470; 0402-TIGHT
R17, R34, R51, R68, R85, R102, R119, R136: 47; 0402-TIGHT
SPARKX1, SPARKX2, SPARKX3, SPARKX4, SPARKX5, SPARKX6, SPARKX7, SPARKX8, SPARKX9, SPARKX10, SPARKX11, SPARKX12, SPARKX13, SPARKX14, SPARKX15, SPARKX16: SPARKX-LOGO4; SPARKX-MEDIUM
TP1, TP2, TP3, TP4, TP5, TP6, TP7, TP8, TP9, TP10, TP11, TP12, TP13, TP14, TP15, TP16, TP17, TP18, TP19, TP20, TP21, TP22, TP23, TP24, TP25, TP26, TP27, TP28, TP29, TP30, TP31, TP32: TEST-POINTTP_15TH_THRU; TP_15TH
U1, U13, U21, U29, U37, U45, U53, U61: 2Mbit SPI Flash; SO08
U2, U12, U20, U28, U36, U44, U52, U60: 1.8V/100mA; SC70
U3, U9, U17, U25, U33, U41, U49, U57: ARTIC_R2; QFN-48
U4, U10, U18, U26, U34, U42, U50, U58: RFPA0133; QFN50P300X300X86-17N
U5, U11, U19, U27, U35, U43, U51, U59: AS179-92LF; SOT65P220X100-6N
U6, U16, U24, U32, U40, U48, U56, U64: 3.0V; SOT23-5
U7, U8, U14, U15, U22, U23, U30, U31, U38, U39, U46, U47, U54, U55, U62, U63: 3.3V; SOT23-5
U$1, U$30, U$57, U$84, U$111, U$138, U$165, U$192: #TX#0
U$2, U$31, U$58, U$85, U$112, U$139, U$166, U$193: #RX#0
U$3, U$22, U$55, U$82, U$109, U$136, U$163, U$190: #RX_LED#0
U$4, U$23, U$56, U$83, U$110, U$137, U$164, U$191: #TX_LED#0
U$5, U$49, U$76, U$103, U$130, U$157, U$184, U$211: #RF_LED#0
U$6, U$54, U$81, U$108, U$135, U$162, U$189, U$216: #G8#0
U$7, U$50, U$77, U$104, U$131, U$158, U$185, U$212: #RF#0
U$8, U$51, U$78, U$105, U$132, U$159, U$186, U$213: #RF_EN#0
U$9, U$32, U$59, U$86, U$113, U$140, U$167, U$194: CIPO#0
U$10, U$33, U$60, U$87, U$114, U$141, U$168, U$195: #CIPO0
U$11, U$34, U$61, U$88, U$115, U$142, U$169, U$196: #COPI0
U$12, U$35, U$62, U$89, U$116, U$143, U$170, U$197: COPI#0
U$13, U$36, U$63, U$90, U$117, U$144, U$171, U$198: #SCLK0
U$14, U$37, U$64, U$91, U$118, U$145, U$172, U$199: SCLK#0
U$15, U$38, U$65, U$92, U$119, U$146, U$173, U$200: #CS0
U$16, U$39, U$66, U$93, U$120, U$147, U$174, U$201: CS#0
U$17, U$43, U$70, U$97, U$124, U$151, U$178, U$205: GND#0
U$18, U$41, U$68, U$95, U$122, U$149, U$176, U$203: #RESETB0
U$19, U$42, U$69, U$96, U$123, U$150, U$177, U$204: #PWR_EN0
U$20, U$52, U$79, U$106, U$133, U$160, U$187, U$214: #VBATT#0
U$21, U$53, U$80, U$107, U$134, U$161, U$188, U$215: #VUSB#0
U$24, U$40, U$67, U$94, U$121, U$148, U$175, U$202: #BOOT0
U$25, U$45, U$72, U$99, U$126, U$153, U$180, U$207: #INT10
U$26, U$44, U$71, U$98, U$125, U$152, U$179, U$206: #INT20
U$27, U$46, U$73, U$100, U$127, U$154, U$181, U$208: #PWR_LED#0
U$28, U$47, U$74, U$101, U$128, U$155, U$182, U$209: #PWR#0
U$29, U$48, U$75, U$102, U$129, U$156, U$183, U$210: ARTIC_R2_BREAKOUT0
X1, X2, X3, X4, X5, X6, X7, X8: CRYSTAL-TCXO-26MHZ; CRYSTAL-TCXO-SMD-1.65X1.25

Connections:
1.8V: C4.1, L2.2, L4.2, L9.2, L13.2, L14.2, TP3.P$1, U2.5
1.8V1: C52.1, L17.2, L19.2, L21.2, L23.2, L30.2, TP7.P$1, U12.5
1.8V2: C100.1, L32.2, L34.2, L36.2, L38.2, L45.2, TP11.P$1, U20.5
1.8V3: C148.1, L47.2, L49.2, L51.2, L53.2, L60.2, TP15.P$1, U28.5
1.8V4: C196.1, L62.2, L64.2, L66.2, L68.2, L75.2, TP19.P$1, U36.5
1.8V5: C244.1, L77.2, L79.2, L81.2, L83.2, L90.2, TP23.P$1, U44.5
1.8V6: C292.1, L92.2, L94.2, L96.2, L98.2, L105.2, TP27.P$1, U52.5
1.8V7: C340.1, L107.2, L109.2, L111.2, L113.2, L120.2, TP31.P$1, U60.5
ANTENNA: C37.1, J1.FEED
ANTENNA1: C51.1, J4.FEED
ANTENNA2: C99.1, J8.FEED
ANTENNA3: C147.1, J11.FEED
ANTENNA4: C195.1, J14.FEED
ANTENNA5: C243.1, J17.FEED
ANTENNA6: C291.1, J20.FEED
ANTENNA7: C339.1, J23.FEED
ARTIC_PWR_EN: J2.8, R1.2, U7.3
ARTIC_PWR_EN1: J3.8, R18.2, U14.3
ARTIC_PWR_EN2: J7.8, R35.2, U22.3
ARTIC_PWR_EN3: J10.8, R52.2, U30.3
ARTIC_PWR_EN4: J13.8, R69.2, U38.3
ARTIC_PWR_EN5: J16.8, R86.2, U46.3
ARTIC_PWR_EN6: J19.8, R103.2, U54.3
ARTIC_PWR_EN7: J22.8, R120.2, U62.3
BOOT: J2.4, R5.1, U3.46
BOOT1: J3.4, R24.1, U9.46
BOOT2: J7.4, R41.1, U17.46
BOOT3: J10.4, R58.1, U25.46
BOOT4: J13.4, R75.1, U33.46
BOOT5: J16.4, R92.1, U41.46
BOOT6: J19.4, R109.1, U49.46
BOOT7: J22.4, R126.1, U57.46
CIPO: J2.16, U3.5
CIPO1: J3.16, U9.5
CIPO2: J7.16, U17.5
CIPO3: J10.16, U25.5
CIPO4: J13.16, U33.5
CIPO5: J16.16, U41.5
CIPO6: J19.16, U49.5
CIPO7: J22.16, U57.5
COPI: J2.17, U3.4
COPI1: J3.17, U9.4
COPI2: J7.17, U17.4
COPI3: J10.17, U25.4
COPI4: J13.17, U33.4
COPI5: J16.17, U41.4
COPI6: J19.17, U49.4
COPI7: J22.17, U57.4
CS: J2.19, U3.2
CS1: J3.19, U9.2
CS2: J7.19, U17.2
CS3: J10.19, U25.2
CS4: J13.19, U33.2
CS5: J16.19, U41.2
CS6: J19.19, U49.2
CS7: J22.19, U57.2
FLSH_CEN: J5.5, U1.1, U3.15
FLSH_CEN1: J6.5, U9.15, U13.1
FLSH_CEN2: J9.5, U17.15, U21.1
FLSH_CEN3: J12.5, U25.15, U29.1
FLSH_CEN4: J15.5, U33.15, U37.1
FLSH_CEN5: J18.5, U41.15, U45.1
FLSH_CEN6: J21.5, U49.15, U53.1
FLSH_CEN7: J24.5, U57.15, U61.1
FLSH_SCLK: J5.3, U1.6, U3.12
FLSH_SCLK1: J6.3, U9.12, U13.6
FLSH_SCLK2: J9.3, U17.12, U21.6
FLSH_SCLK3: J12.3, U25.12, U29.6
FLSH_SCLK4: J15.3, U33.12, U37.6
FLSH_SCLK5: J18.3, U41.12, U45.6
FLSH_SCLK6: J21.3, U49.12, U53.6
FLSH_SCLK7: J24.3, U57.12, U61.6
FLSH_SI: J5.4, U1.5, U3.13
FLSH_SI1: J6.4, U9.13, U13.5
FLSH_SI2: J9.4, U17.13, U21.5
FLSH_SI3: J12.4, U25.13, U29.5
FLSH_SI4: J15.4, U33.13, U37.5
FLSH_SI5: J18.4, U41.13, U45.5
FLSH_SI6: J21.4, U49.13, U53.5
FLSH_SI7: J24.4, U57.13, U61.5
FLSH_SO: J5.1, U1.2, U3.14
FLSH_SO1: J6.1, U9.14, U13.2
FLSH_SO2: J9.1, U17.14, U21.2
FLSH_SO3: J12.1, U25.14, U29.2
FLSH_SO4: J15.1, U33.14, U37.2
FLSH_SO5: J18.1, U41.14, U45.2
FLSH_SO6: J21.1, U49.14, U53.2
FLSH_SO7: J24.1, U57.14, U61.2
FLSH_VCC: C2.1, C45.1, J5.2, L1.1, R2.2, R11.2, U1.8
FLSH_VCC1: C55.1, C56.1, J6.2, L16.1, R19.2, R20.2, U13.8
FLSH_VCC2: C103.1, C104.1, J9.2, L31.1, R36.2, R37.2, U21.8
FLSH_VCC3: C151.1, C152.1, J12.2, L46.1, R53.2, R54.2, U29.8
FLSH_VCC4: C199.1, C200.1, J15.2, L61.1, R70.2, R71.2, U37.8
FLSH_VCC5: C247.1, C248.1, J18.2, L76.1, R87.2, R88.2, U45.8
FLSH_VCC6: C295.1, C296.1, J21.2, L91.1, R104.2, R105.2, U53.8
FLSH_VCC7: C343.1, C344.1, J24.2, L106.1, R121.2, R122.2, U61.8
G1: J3.3, K2.1
G2: J7.3, K3.1
G3: J10.3, K4.1
G4: J13.3, K5.1
G5: J16.3, K6.1
G6: J19.3, K7.1
G7: J22.3, K8.1
G8: J2.3, K1.1
GND: C1.2, C2.2, C3.2, C4.2, C5.2, C6.2, C7.2, C8.2, C9.2, C10.2, C11.2, C12.2, C13.2, C14.2, C15.2, C16.2, C18.2, C19.2, C20.1, C21.1, C22.1, C23.2, C26.2, C27.2, C28.1, C32.2, C33.2, C34.2, C35.2, C36.2, C38.2, C39.2, C40.2, C41.2, C42.2, C43.1, C44.2, C45.2, C46.2, C47.2, C48.2, J1.1, J1.2, J2.25, J5.6, JP3.1, JP4.1, JP5.1, JP6.1, K1.2, L11.P$1, L12.P$1, R1.1, R4.2, R6.1, R7.2, R10.1, R14.1, R16.1, U1.4, U2.2, U3.25, U3.27, U3.29, U3.30, U3.31, U3.32, U3.39, U3.GND, U4.2, U4.EDAP, U5.2, U6.2, U7.2, U8.2, X1.1, X1.2
GND1: C52.2, C53.2, C54.2, C55.2, C56.2, C57.2, C58.2, C59.2, C60.2, C61.2, C62.2, C63.2, C64.2, C65.2, C66.2, C67.2, C68.2, C69.2, C70.2, C71.2, C72.2, C74.2, C75.2, C76.2, C79.1, C80.1, C81.1, C82.2, C83.2, C85.1, C86.2, C87.2, C88.2, C89.1, C90.2, C91.2, C92.2, C93.2, C94.2, C95.2, C96.2, J3.25, J4.1, J4.2, J6.6, JP1.1, JP2.1, JP7.1, JP8.1, K2.2, L28.P$1, L29.P$1, R18.1, R25.2, R26.1, R27.2, R30.1, R32.1, R33.1, U9.25, U9.27, U9.29, U9.30, U9.31, U9.32, U9.39, U9.GND, U10.2, U10.EDAP, U11.2, U12.2, U13.4, U14.2, U15.2, U16.2, X2.1, X2.2
GND2: C100.2, C101.2, C102.2, C103.2, C104.2, C105.2, C106.2, C107.2, C108.2, C109.2, C110.2, C111.2, C112.2, C113.2, C114.2, C115.2, C116.2, C117.2, C118.2, C119.2, C120.2, C122.2, C123.2, C124.2, C127.1, C128.1, C129.1, C130.2, C131.2, C133.1, C134.2, C135.2, C136.2, C137.1, C138.2, C139.2, C140.2, C141.2, C142.2, C143.2, C144.2, J7.25, J8.1, J8.2, J9.6, JP9.1, JP10.1, JP11.1, JP12.1, K3.2, L43.P$1, L44.P$1, R35.1, R42.2, R43.1, R44.2, R47.1, R49.1, R50.1, U17.25, U17.27, U17.29, U17.30, U17.31, U17.32, U17.39, U17.GND, U18.2, U18.EDAP, U19.2, U20.2, U21.4, U22.2, U23.2, U24.2, X3.1, X3.2
GND3: C148.2, C149.2, C150.2, C151.2, C152.2, C153.2, C154.2, C155.2, C156.2, C157.2, C158.2, C159.2, C160.2, C161.2, C162.2, C163.2, C164.2, C165.2, C166.2, C167.2, C168.2, C170.2, C171.2, C172.2, C175.1, C176.1, C177.1, C178.2, C179.2, C181.1, C182.2, C183.2, C184.2, C185.1, C186.2, C187.2, C188.2, C189.2, C190.2, C191.2, C192.2, J10.25, J11.1, J11.2, J12.6, JP13.1, JP14.1, JP15.1, JP16.1, K4.2, L58.P$1, L59.P$1, R52.1, R59.2, R60.1, R61.2, R64.1, R66.1, R67.1, U25.25, U25.27, U25.29, U25.30, U25.31, U25.32, U25.39, U25.GND, U26.2, U26.EDAP, U27.2, U28.2, U29.4, U30.2, U31.2, U32.2, X4.1, X4.2
GND4: C196.2, C197.2, C198.2, C199.2, C200.2, C201.2, C202.2, C203.2, C204.2, C205.2, C206.2, C207.2, C208.2, C209.2, C210.2, C211.2, C212.2, C213.2, C214.2, C215.2, C216.2, C218.2, C219.2, C220.2, C223.1, C224.1, C225.1, C226.2, C227.2, C229.1, C230.2, C231.2, C232.2, C233.1, C234.2, C235.2, C236.2, C237.2, C238.2, C239.2, C240.2, J13.25, J14.1, J14.2, J15.6, JP17.1, JP18.1, JP19.1, JP20.1, K5.2, L73.P$1, L74.P$1, R69.1, R76.2, R77.1, R78.2, R81.1, R83.1, R84.1, U33.25, U33.27, U33.29, U33.30, U33.31, U33.32, U33.39, U33.GND, U34.2, U34.EDAP, U35.2, U36.2, U37.4, U38.2, U39.2, U40.2, X5.1, X5.2
GND5: C244.2, C245.2, C246.2, C247.2, C248.2, C249.2, C250.2, C251.2, C252.2, C253.2, C254.2, C255.2, C256.2, C257.2, C258.2, C259.2, C260.2, C261.2, C262.2, C263.2, C264.2, C266.2, C267.2, C268.2, C271.1, C272.1, C273.1, C274.2, C275.2, C277.1, C278.2, C279.2, C280.2, C281.1, C282.2, C283.2, C284.2, C285.2, C286.2, C287.2, C288.2, J16.25, J17.1, J17.2, J18.6, JP21.1, JP22.1, JP23.1, JP24.1, K6.2, L88.P$1, L89.P$1, R86.1, R93.2, R94.1, R95.2, R98.1, R100.1, R101.1, U41.25, U41.27, U41.29, U41.30, U41.31, U41.32, U41.39, U41.GND, U42.2, U42.EDAP, U43.2, U44.2, U45.4, U46.2, U47.2, U48.2, X6.1, X6.2
GND6: C292.2, C293.2, C294.2, C295.2, C296.2, C297.2, C298.2, C299.2, C300.2, C301.2, C302.2, C303.2, C304.2, C305.2, C306.2, C307.2, C308.2, C309.2, C310.2, C311.2, C312.2, C314.2, C315.2, C316.2, C319.1, C320.1, C321.1, C322.2, C323.2, C325.1, C326.2, C327.2, C328.2, C329.1, C330.2, C331.2, C332.2, C333.2, C334.2, C335.2, C336.2, J19.25, J20.1, J20.2, J21.6, JP25.1, JP26.1, JP27.1, JP28.1, K7.2, L103.P$1, L104.P$1, R103.1, R110.2, R111.1, R112.2, R115.1, R117.1, R118.1, U49.25, U49.27, U49.29, U49.30, U49.31, U49.32, U49.39, U49.GND, U50.2, U50.EDAP, U51.2, U52.2, U53.4, U54.2, U55.2, U56.2, X7.1, X7.2
GND7: C340.2, C341.2, C342.2, C343.2, C344.2, C345.2, C346.2, C347.2, C348.2, C349.2, C350.2, C351.2, C352.2, C353.2, C354.2, C355.2, C356.2, C357.2, C358.2, C359.2, C360.2, C362.2, C363.2, C364.2, C367.1, C368.1, C369.1, C370.2, C371.2, C373.1, C374.2, C375.2, C376.2, C377.1, C378.2, C379.2, C380.2, C381.2, C382.2, C383.2, C384.2, J22.25, J23.1, J23.2, J24.6, JP29.1, JP30.1, JP31.1, JP32.1, K8.2, L118.P$1, L119.P$1, R120.1, R127.2, R128.1, R129.2, R132.1, R134.1, R135.1, U57.25, U57.27, U57.29, U57.30, U57.31, U57.32, U57.39, U57.GND, U58.2, U58.EDAP, U59.2, U60.2, U61.4, U62.2, U63.2, U64.2, X8.1, X8.2
INT1: J2.5, U3.47
INT2: J2.6, U3.48
INT3: J3.6, U9.48
INT4: J3.5, U9.47
INT5: J7.6, U17.48
INT6: J7.5, U17.47
INT7: J10.6, U25.48
INT8: J10.5, U25.47
INT9: J13.6, U33.48
INT10: J13.5, U33.47
INT11: J16.6, U41.48
INT12: J16.5, U41.47
INT13: J19.6, U49.48
INT14: J19.5, U49.47
INT15: J22.6, U57.48
INT16: J22.5, U57.47
unnamed: C49.1, U11.1
unnamed: R2.1, U1.7
unnamed: R11.1, U1.3
unnamed: C34.1, C35.1, L13.1, U3.24
unnamed: C40.1, C41.1, L15.1, U3.23
unnamed: D2.A, R13.1
unnamed: D1.A, R12.1
unnamed: C26.1, C27.1, L9.1, U3.6
unnamed: C32.1, C33.1, L10.1, R5.2, R8.1, U3.9
unnamed: C11.1, C12.1, C13.1, L4.1, U3.28, U3.33, U3.35
unnamed: C7.1, C8.1, L3.1, U3.36
unnamed: R4.1, U3.41
unnamed: C5.1, C6.1, L2.1, U3.40
unnamed: C9.1, C10.1, U3.37, X1.4
unnamed: C17.1, X1.3
unnamed: C17.2, U3.38
unnamed: C24.1, U3.34
unnamed: C24.2, C25.1, R6.2
unnamed: L5.P$2, U4.14
unnamed: C15.1, C18.1, L5.P$1, R3.1
unnamed: C29.P$1, L11.P$2, U3.26
unnamed: D4.A, R9.1
unnamed: C50.1, U11.3
unnamed: C25.2, L7.P$1
unnamed: L7.P$2, U4.3
unnamed: L6.P$2, L8.P$1, U4.9, U4.10
unnamed: D4.C, JP6.2
unnamed: C31.1, U5.1
unnamed: C30.1, U5.3
unnamed: C37.2, U5.5
unnamed: C38.1, C39.1, L14.1, U3.20
unnamed: C51.2, U11.5
unnamed: R19.1, U13.7
unnamed: R20.1, U13.3
unnamed: D1.C, JP3.2
unnamed: D2.C, JP4.2
unnamed: D3.A, R15.1
unnamed: D3.C, JP5.2
unnamed: C59.1, C60.1, L17.1, U9.24
unnamed: C61.1, C62.1, L18.1, U9.23
unnamed: D7.A, R22.1
unnamed: D6.A, R21.1
unnamed: C63.1, C64.1, L19.1, U9.6
unnamed: C65.1, C66.1, L20.1, R23.1, R24.2, U9.9
unnamed: C74.1, C75.1, C76.1, L21.1, U9.28, U9.33, U9.35
unnamed: C67.1, C68.1, L22.1, U9.36
unnamed: R25.1, U9.41
unnamed: C69.1, C70.1, L23.1, U9.40
unnamed: C71.1, C72.1, U9.37, X2.4
unnamed: C73.1, X2.3
unnamed: C73.2, U9.38
unnamed: C77.1, U9.34
unnamed: C77.2, C78.1, R26.2
unnamed: L25.P$2, U10.14
unnamed: C82.1, C83.1, L25.P$1, R28.1
unnamed: C78.2, L24.P$1
unnamed: L24.P$2, U10.3
unnamed: L26.P$2, L27.P$1, U10.9, U10.10
unnamed: C84.P$1, L28.P$2, U9.26
unnamed: C91.1, C92.1, L30.1, U9.20
unnamed: D6.C, JP1.2
unnamed: D7.C, JP2.2
unnamed: D8.A, R29.1
unnamed: D8.C, JP7.2
unnamed: D9.A, R31.1
unnamed: D9.C, JP8.2
unnamed: C97.1, U19.1
unnamed: C98.1, U19.3
unnamed: C99.2, U19.5
unnamed: R36.1, U21.7
unnamed: R37.1, U21.3
unnamed: C107.1, C108.1, L32.1, U17.24
unnamed: C109.1, C110.1, L33.1, U17.23
unnamed: D12.A, R39.1
unnamed: D11.A, R38.1
unnamed: C111.1, C112.1, L34.1, U17.6
unnamed: C113.1, C114.1, L35.1, R40.1, R41.2, U17.9
unnamed: C122.1, C123.1, C124.1, L36.1, U17.28, U17.33, U17.35
unnamed: C115.1, C116.1, L37.1, U17.36
unnamed: R42.1, U17.41
unnamed: C117.1, C118.1, L38.1, U17.40
unnamed: C119.1, C120.1, U17.37, X3.4
unnamed: C121.1, X3.3
unnamed: C121.2, U17.38
unnamed: C125.1, U17.34
unnamed: C125.2, C126.1, R43.2
unnamed: L40.P$2, U18.14
unnamed: C130.1, C131.1, L40.P$1, R45.1
unnamed: C126.2, L39.P$1
unnamed: L39.P$2, U18.3
unnamed: L41.P$2, L42.P$1, U18.9, U18.10
unnamed: C132.P$1, L43.P$2, U17.26
unnamed: C139.1, C140.1, L45.1, U17.20
unnamed: D11.C, JP9.2
unnamed: D12.C, JP10.2
unnamed: D13.A, R46.1
unnamed: D13.C, JP11.2
unnamed: D14.A, R48.1
unnamed: D14.C, JP12.2
unnamed: C145.1, U27.1
unnamed: C146.1, U27.3
unnamed: C147.2, U27.5
unnamed: R53.1, U29.7
unnamed: R54.1, U29.3
unnamed: C155.1, C156.1, L47.1, U25.24
unnamed: C157.1, C158.1, L48.1, U25.23
unnamed: D17.A, R56.1
unnamed: D16.A, R55.1
unnamed: C159.1, C160.1, L49.1, U25.6
unnamed: C161.1, C162.1, L50.1, R57.1, R58.2, U25.9
unnamed: C170.1, C171.1, C172.1, L51.1, U25.28, U25.33, U25.35
unnamed: C163.1, C164.1, L52.1, U25.36
unnamed: R59.1, U25.41
unnamed: C165.1, C166.1, L53.1, U25.40
unnamed: C167.1, C168.1, U25.37, X4.4
unnamed: C169.1, X4.3
unnamed: C169.2, U25.38
unnamed: C173.1, U25.34
unnamed: C173.2, C174.1, R60.2
unnamed: L55.P$2, U26.14
unnamed: C178.1, C179.1, L55.P$1, R62.1
unnamed: C174.2, L54.P$1
unnamed: L54.P$2, U26.3
unnamed: L56.P$2, L57.P$1, U26.9, U26.10
unnamed: C180.P$1, L58.P$2, U25.26
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

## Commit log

2020-07-27 Work in progress
    [ARTIC_R2.brd, ARTIC_R2.sch]
2020-07-27 Nearing completion
    [ARTIC_R2.brd, ARTIC_R2.sch]
2020-07-27 Adjusted the RF track widths
    [ARTIC_R2.brd, ARTIC_R2.sch]
2020-07-28 Added 4x4 test panel
    [ARTIC_R2-Panel.GBL, ARTIC_R2-Panel.GBO, ARTIC_R2-Panel.GBP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]
2020-07-29 ).8mm PCB with Impedance Control
    [ARTIC_R2-Panel.brd, ARTIC_R2.brd, ARTIC_R2.sch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]
2020-09-15 Updated the flash memory
    [ARTIC_R2.brd, ARTIC_R2.sch]
2020-09-15 PROD_ID updates
    [ARTIC_R2.brd, ARTIC_R2.sch]
2020-09-15 Added the missing PROD_IDs
    [ARTIC_R2.brd, ARTIC_R2.sch]
2020-10-15 X02 - just about complete
    [ARTIC_R2.brd, ARTIC_R2.sch]
2020-10-16 Updates for X02
    [ARTIC_R2-Panel.GBL, ARTIC_R2-Panel.GBO, ARTIC_R2-Panel.GBS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]
2020-10-16 Adding the PROD_ID for the Toshiba photorelay
    [ARTIC_R2.brd, ARTIC_R2.sch]
2020-11-13 Adding the BOM
    [ARTIC_R2_BOM.csv]
2020-11-15 Changing R7 from 10K to 1K
    [ARTIC_R2.brd, ARTIC_R2.sch, ARTIC_R2_BOM.csv]
2020-11-19 Adding the board images
2020-12-03 Updates for X03. Design now includes a 3.0V regulator for the RF amp gain and bias.
    [ARTIC_R2-Panel.brd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]
2020-12-07 Final tweaks for X03. Changed 8dB to G8. Increased annular ring to 3.5mil.
    [ARTIC_R2-Panel.brd, ARTIC_R2.brd, ARTIC_R2.sch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]
2020-12-07 Correcting the description of the G8 pin - for version X03 of the PCB
2020-12-08 Adding the missing PROD_IDs
    [ARTIC_R2.brd, ARTIC_R2.sch, ARTIC_R2_BOM.csv]
2021-03-22 Adding our antenna datasheet
2021-03-22 Adding current draw
2021-11-22 Update Eagle files - remove New_Parts.lbr
    [ARTIC_R2.brd, ARTIC_R2.sch, ARTIC_R2_BOM.csv]

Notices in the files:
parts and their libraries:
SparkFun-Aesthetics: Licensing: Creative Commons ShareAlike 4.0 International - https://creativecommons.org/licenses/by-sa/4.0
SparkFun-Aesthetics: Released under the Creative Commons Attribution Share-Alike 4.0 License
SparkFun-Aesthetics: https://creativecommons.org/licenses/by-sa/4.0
